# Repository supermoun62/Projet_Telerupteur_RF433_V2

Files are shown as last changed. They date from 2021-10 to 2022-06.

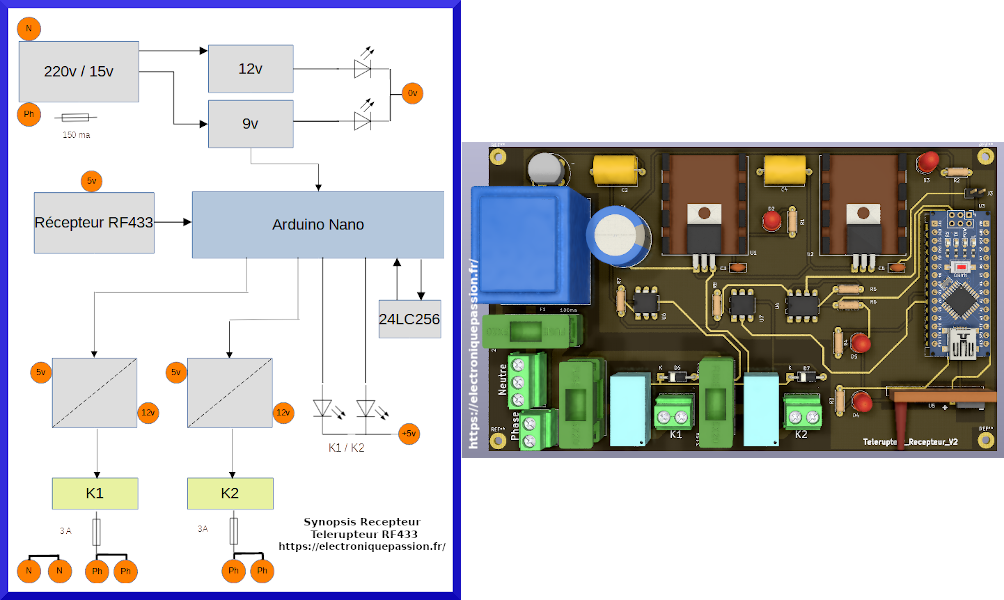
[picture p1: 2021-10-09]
Synopsis_PCB_Telerupteur_Recepteur_V2.png

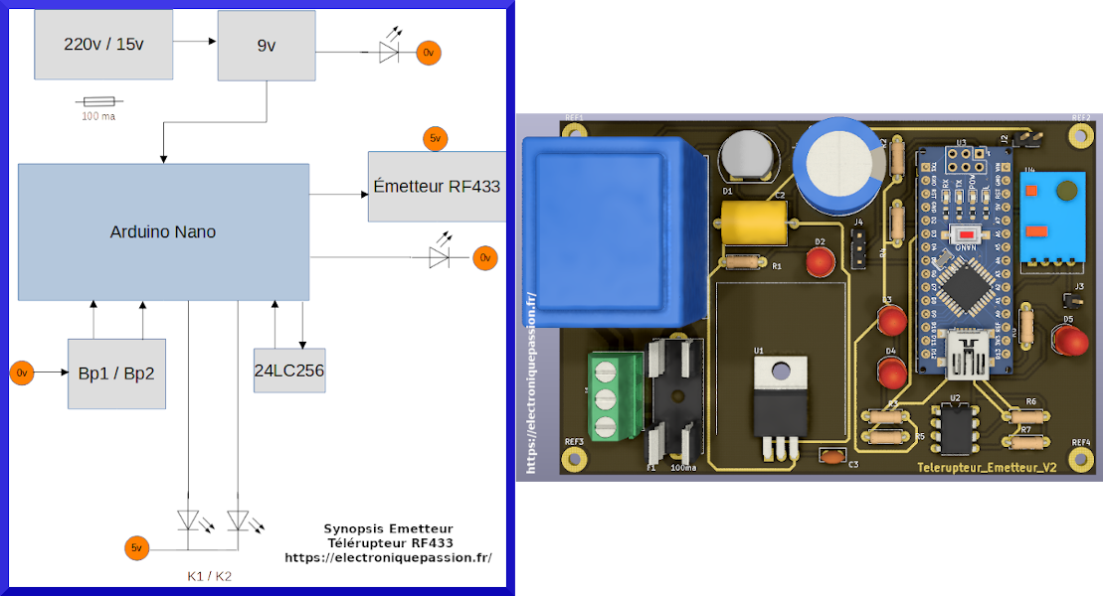
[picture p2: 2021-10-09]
Synopsis_PCB_Telerupteur_Emetteur_V2.png

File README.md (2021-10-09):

# Projet_Telerupteur_RF433_V2
Piloter des relais en RF433. L'ensemble comprend:

    Programmes Arduino de l'émetteur et du récepteur.

    Programmes Arduino Test.

    Librairies VirtualWire et simpleBouton.

    Liste du matériel.

    Les schémas (Emetteur, Récepteur).

    Documentations Techniques.

    PCB en Gerber.

    PCB en PDF.

    Le fichier Projet Telerupteur_RF433_V2.pdf contient le détail du projet.

    https://github.com/supermoun62/Projet_Telerupteur_RF433_V2/blob/main/Synopsis_PCB_Telerupteur_Emetteur_V2.png

    https://github.com/supermoun62/Projet_Telerupteur_RF433_V2/blob/main/Synopsis_PCB_Telerupteur_Recepteur_V2.png

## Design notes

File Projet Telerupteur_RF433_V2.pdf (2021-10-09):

## Projet Télérupteur_RF433_V1 Projet

Arduino_Cde_Telerupteur_RF433_V2 | 1 sur 15 | https://electroniquepassion.fr/

# PROJET

Piloter deux relais en RF433.

Mémoriser l’état de la commande de chaque relais en cas de coupure de courant de l’émetteur.

## Plus d’info pour récupérer le projet sur le site:

## https://electroniquepassion.fr

## Projet Télérupteur_RF433_V1 Synopsis Emetteur

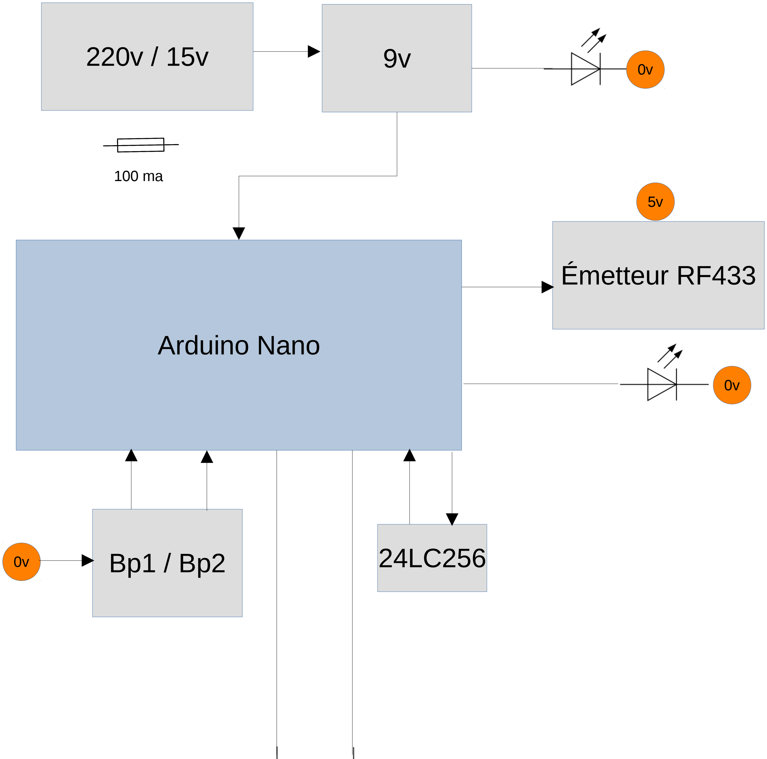
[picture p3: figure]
Arduino Nano; Émetteur RF433

5v
K1 / K2
Arduino_Cde_Telerupteur_RF433_V2 | 2 sur 15 | https://electroniquepassion.fr/

## Projet Télérupteur_RF433_V1 Synopsis Récepteur

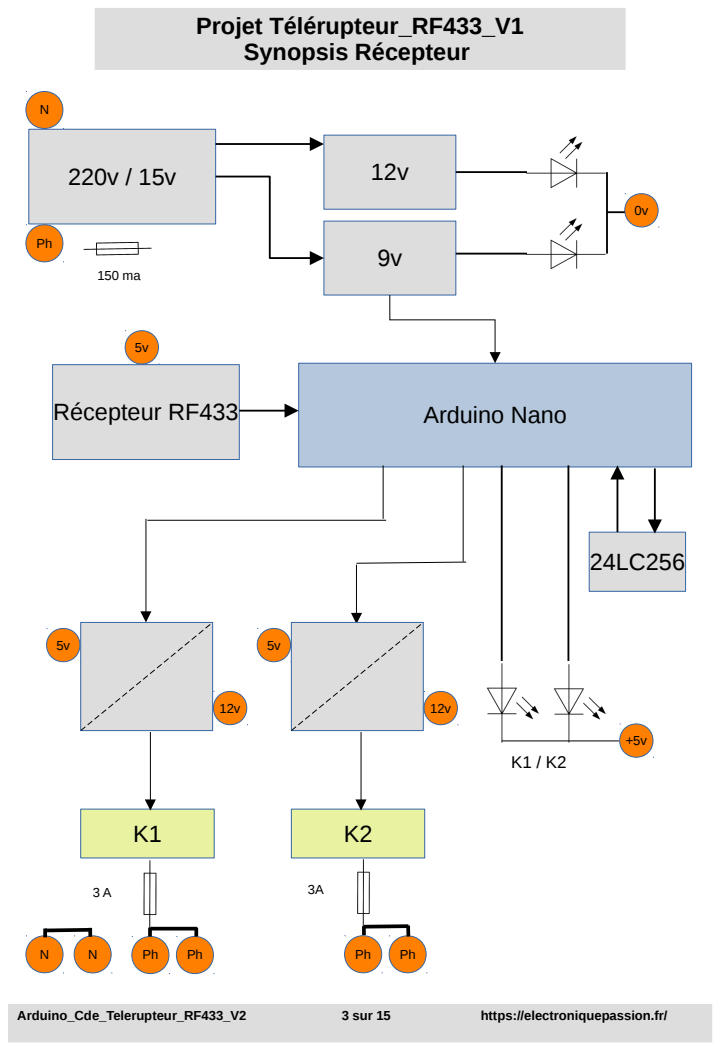
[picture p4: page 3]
Récepteur RF433; Arduino Nano; Arduino_Cde_Telerupteur_RF433_V2; 3 sur 15; https://electroniquepassion.fr/

## Dossier Matériels:

Projet_Telerupteur_RF433_V2\ Liste_Materiel_Emetteur_Recepteur_Telerupteur_RF433_V2

## Dossiers Documentations Techniques:

Projet_Telerupteur_RF433_V2\Doc_Tech_Emetteur_Recepteur_Telerupteur_RF433_V2

## Dossiers Schémas:

Projet_Telerupteur_RF433_V2\Schemas_Emetteur_Recepteur_Telerupteur_RF433_V2

## Dossiers PCB Emetteur en Gerber

Projet_Telerupteur_RF433_V2\PCB_GERBER_Telerupteur_Emetteur_V2

## Dossiers PCB Emetteur en PDF

Projet_Telerupteur_RF433_V2\PCB_PDF_Telerupteur_Emetteur_V2

## Programme Arduino Emetteur :

Projet_Telerupteur_RF433_V2\ArduinoTelerupteurEmissionRF433_V2

## Dossiers PCB Recepteur en Gerber

Projet_Telerupteur_RF433_V2\PCB_GERBER_Telerupteur_Recepteur_V2

## Dossiers PCB Emetteur en PDF

Projet_Telerupteur_RF433_V2\PCB_PDF_Telerupteur_Recepteur_V2

## Programme Arduino Récepteur :

Projet_Telerupteur_RF433_V2\ArduinoTelerupteurReceptionRF433_V2

## Projet Télérupteur_RF433_V1

Arduino_Cde_Telerupteur_RF433_V2 | 4 sur 15 | https://electroniquepassion.fr/

## Projet Télérupteur_RF433_V1

## Librairies:

Dossier VirtualWire13

VirtualWire V1,3 (http://www.airspayce.com/mikem/arduino/VirtualWire/index.html) | Airspace (https://www.airspayce.com/mikem/arduino/VirtualWire/VirtualWire_8h.html) | Github (https://github.com/m0/Updated-Arduino-VirtualWire-Library) | CarnetduMaker (https://www.carnetdumaker.net/articles/communiquer-sans-fil-en-433mhz-avec-la-bibliotheque-virtualwire-et-une-carte-arduino-genuino/)

Pjrc (https://www.pjrc.com/teensy/td_libs_VirtualWire.html)

Dossier simpleBouton V1.4.2

SimpleBouton (https://forum.arduino.cc/index.php?topic=375232.0)

24LC256 :

Lien 1 (https://lesiteferroviaire.pagesperso-orange.fr/Memoire%2024LC512.htm) | | Lien2 (http://electroniqueamateur.blogspot.com/2020/01/utiliser-une-memoire-eeprom-i2c-arduino.html) | Lien 3 (https://www.youtube.com/watch?v=9CpwQUzw1ys)

## Lecture totale 24LC256

Projet_Telerupteur_RF433_V2\24LC256LectureTotale

## Lecture - Ecriture 24LC256 :

Projet_Telerupteur_RF433_V2\ArduinoLectureEcriture_24LC256

## Test reception messages :

Projet_Telerupteur_RF433_V2\ArduinoTestReceptionMessage

## Programmes utilises :

LibreOffice Calc, LibreOffice Draw, Arduino,
Kicad, Freecad, FreeRouting Gimp
Arduino_Cde_Telerupteur_RF433_V2 | 5 sur 15 | https://electroniquepassion.fr/

## Fonctions de la librairie VirtualWire sont les suivantes:

extern void vw_set_tx_pin(uint8_t pin);

Pin utilisée pour transmettre les données, par défaut D12 de l’Arduino.

extern void vw_set_rx_pin(uint8_t pin);

Pin utilisée pour recevoir les données, par défaut D11 de l’Arduino.

extern void vw_set_ptt_pin(uint8_t pin); par défaut D10 de l’Arduino.

extern void vw_setup(uint16_t speed)

extern void vw_rx_start();

extern void vw_rx_stop();

extern uint8_t vx_tx_active();

extern void vw_wait_tx();

extern void vw_wait_rx();

extern uint8_t vw_wait_rx_max(unsigned long milliseconds);

extern uint8_t vw_send(uint8_t* buf, uint8_t len);

vw_send(byte* buf, byte len);

extern uint8_t vw_have_message();

extern uint8_t vw_get_message(uint8_t* buf, uint8_t* len); .

vw_MAX_MESSAGE_LEN ;

## D10, D11, D12 utilisées par défaut par Wirtualwire

## Arduino_Cde_Télérupteur_RF433_V1

Arduino_Cde_Telerupteur_RF433_V2 | 6 sur 15 | https://electroniquepassion.fr/

le 1/4 d'onde est la plus classique et la meilleure des antenne fouet (conducteur normal cuivre rigide ) longueur onde entière = vitesse de la lumière / fréquence
soit : 300 000 / 433 = 693 mm
1/4 d'onde = 173 mm

On peut réduire le résultat à 95%,
(effet de bout) donc 164,3 mm

## Site Lucea (http://www.lucea.fr/spip.php?article4)

## Fil utilisé pour l’antenne pendant les

essais.

## 35m sans obstacle

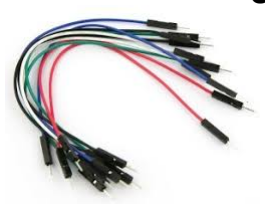
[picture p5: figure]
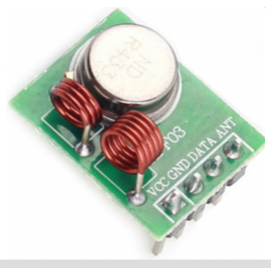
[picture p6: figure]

SEED STUDIO réf :113990010

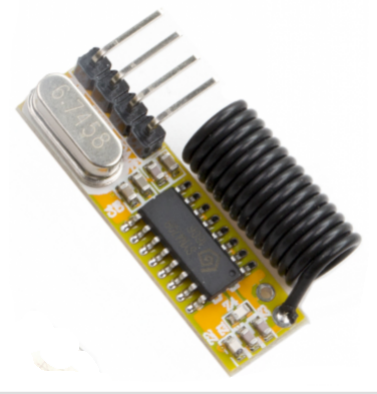
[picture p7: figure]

SEED STUDIO réf :113990010

Arduino_Cde_Telerupteur_RF433_V2 | 7 sur 15 | https://electroniquepassion.fr/

## Emetteur Calcul Refroidisseur Régulateur

Méthode utilisée : ICI (https://migia.pagesperso-orange.fr/electron/radiateur/radiateur.htm)

Rth ja | : 50°C/W
Rth jc | : 5°C/W
Tj Max | : 0-125° Prenons 100°
Ta | : 35°
Pâte | : 0,1°C/W
Is | : 0,2A

(5 + 0,1 + SA)

(100 - 35)
2 =

(Jc + CS + SA)

(Tj - Ta)
Pd =

2

65 – 10,2
SA =

SA = 27,4ºC/W Maximum

Pd = (Ue-Us)*I

(21-12)*0,2A = 1,8w, Prenons 2w

Lien 1 (https://fr.wikipedia.org/wiki/Loi_d'Ohm_thermique) | Lien 2 (https://migia.pagesperso-orange.fr/electron/radiateur/radiateur.htm) | Lien 3 (http://gdedel95.free.fr/STSETT/STS%20ETT2_2005-2006/Pdf/Choix%20dissipateur.PDF)
Arduino_Cde_Telerupteur_RF433_V2 | 8 sur 15 | https://electroniquepassion.fr/

## Emetteur

4N35

Lien1 (https://www.astuces-pratiques.fr/electronique/l-optocoupleur-principe-de-fonctionnement)

Pour les essais, j’ai utilisé le Joy-IT Nano-V3 de chez Joy-It.

Pour information, nécessite le driver : CH341SER.

Pour télécharger le programme, j'ai choisi :
ATmega328P (Old Bootloader)

Voir les infos sur la page :

## Joy-It (https://joy-it.net/en/products/ARD_NanoV3)

Arduino_Cde_Telerupteur_RF433_V2 | 9 sur 15 | https://electroniquepassion.fr/

## PCB Emetteur

Tracé du PCB :

Projet_Telerupteur_RF433_V2\

PCB_PDF_Telerupteur_Emetteur_V2\Telerupteur_Emetteur_RF433_V2-B_Cu.pdf

PCB_PDF_Telerupteur_Emetteur_V2\Telerupteur_Emetteur_RF433_V2-F_Cu.pdf

Implantation Composants :

Projet_Telerupteur_RF433_V2\

PCB_PDF_Telerupteur_Emetteur_V2\Telerupteur_Emetteur_RF433_V2-F_SilkS.pdf

Création du PCB

- Fabrication personnelle OU
- Sites en ligne comme :
Util'Pocket
JLCPCB
Etc....

Chez JLCPCB nécessite l'envoi du dossier compressé :

PCB_GERBER_Telerupteur_Emetteur_V2

Arduino_Cde_Telerupteur_RF433_V2 | 10 sur 15 | https://electroniquepassion.fr/

## PCB Emetteur

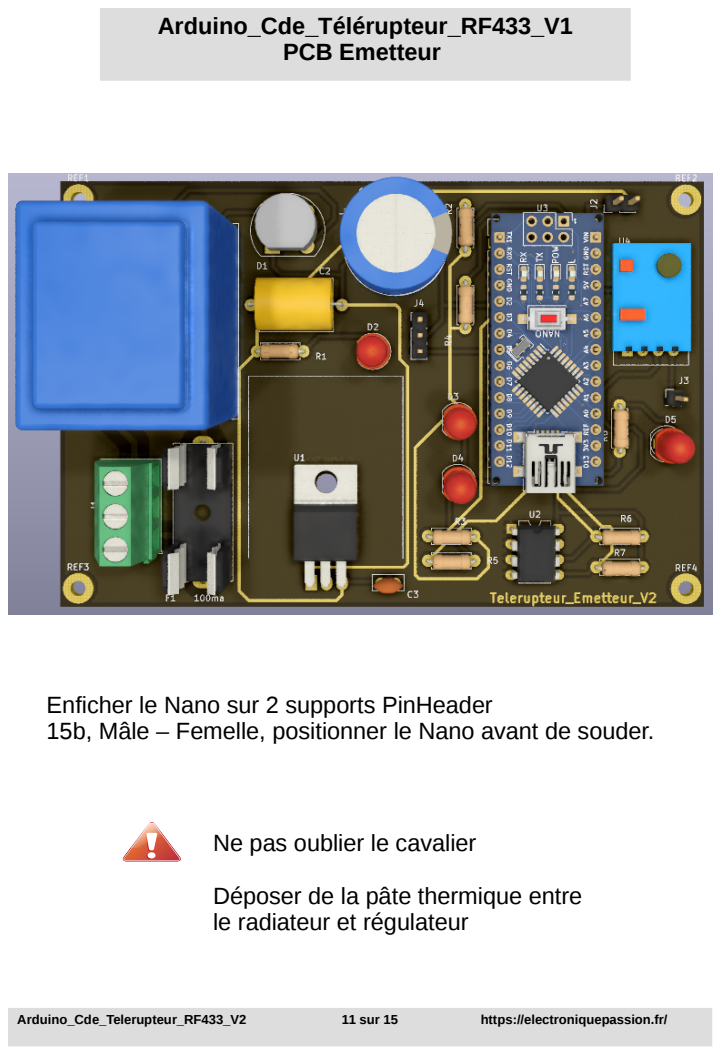
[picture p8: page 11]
Arduino_Cde_Telerupteur_RF433_V2; 11 sur 15; https://electroniquepassion.fr/

Enficher le Nano sur 2 supports PinHeader
15b, Mâle – Femelle, positionner le Nano avant de souder.

Ne pas oublier le cavalier

Déposer de la pâte thermique entre
le radiateur et régulateur

## PCB Tracé Emetteur

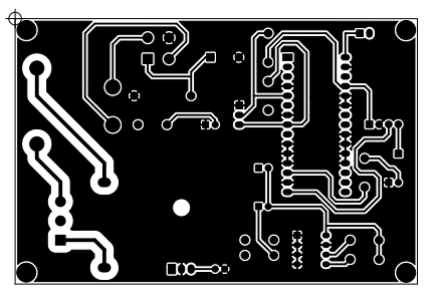
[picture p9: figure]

## Telerupteur_Emetteur_RF433_V2-B_Cu.pdf

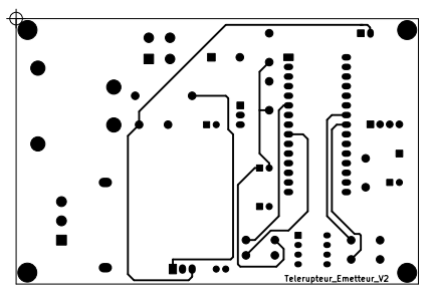
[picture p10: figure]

## Telerupteur_Emetteur_RF433_V2-F_Cu.pdf

Images pas
à l’échelle
Arduino_Cde_Telerupteur_RF433_V2 | 12 sur 15 | https://electroniquepassion.fr/

## PCB Récepteur

Tracé du PCB :

Projet_Telerupteur_RF433_V2\

PCB_PDF_Telerupteur_Recepteur_V2\Telerupteur_Recepteur_RF433_V2-B_Cu.pdf

PCB_PDF_Telerupteur_Recepteur_V2\Telerupteur_Recepteur_RF433_V2-F_Cu.pdf

Implantation Composants :

Projet_Telerupteur_RF433_V2\

PCB_PDF_Telerupteur_Recepteur_V2\Telerupteur_Recepteur_RF433_V2-F_SilkS.pdf

Création du PCB

- Fabrication personnelle OU
- Sites en ligne comme :
Util'Pocket
JLCPCB
Etc....

Chez JLCPCB nécessite l'envoi du dossier compressé :

PCB_GERBER_Telerupteur_Recepteur_V2

Arduino_Cde_Telerupteur_RF433_V2 | 13 sur 15 | https://electroniquepassion.fr/

## PCB Récepteur

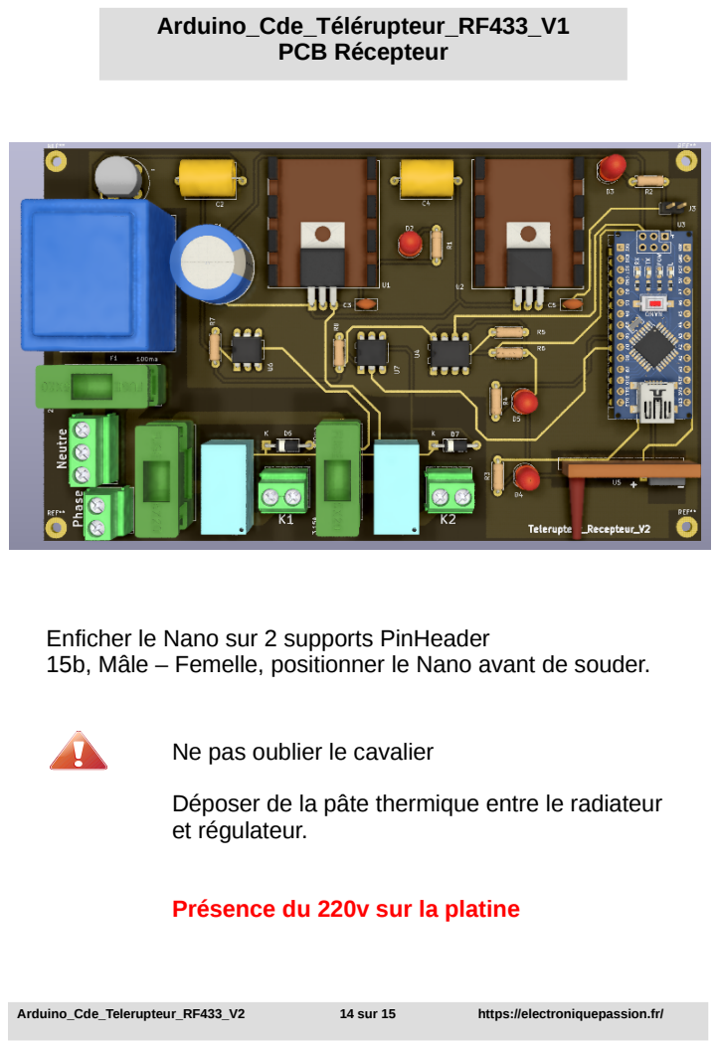
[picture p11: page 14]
Arduino_Cde_Telerupteur_RF433_V2; 14 sur 15; https://electroniquepassion.fr/

Enficher le Nano sur 2 supports PinHeader
15b, Mâle – Femelle, positionner le Nano avant de souder.

Ne pas oublier le cavalier

Déposer de la pâte thermique entre le radiateur
et régulateur.

Présence du 220v sur la platine

## PCB tracé Récepteur

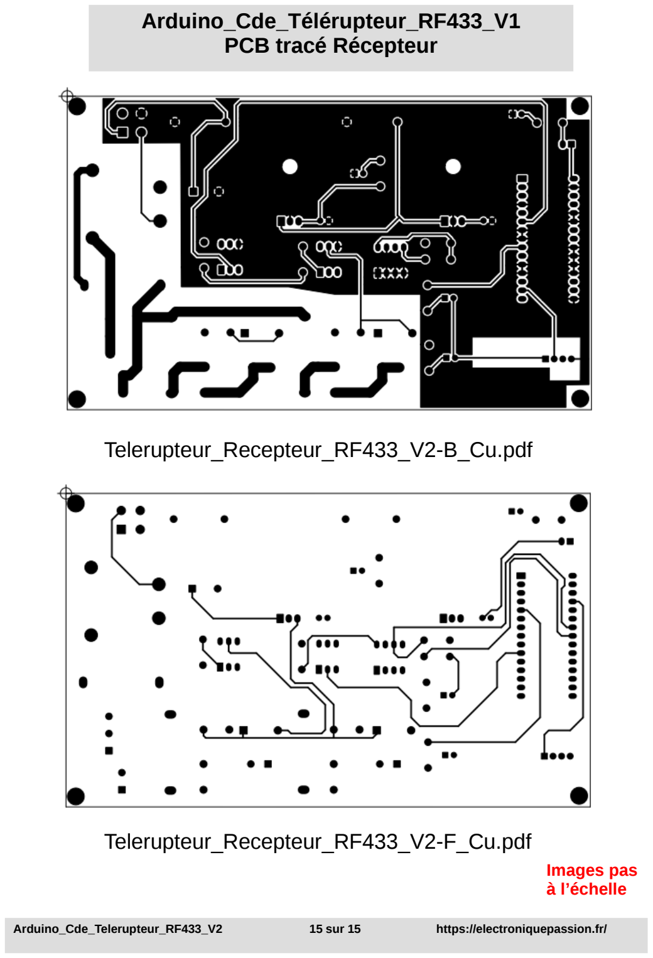
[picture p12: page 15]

## Telerupteur_Recepteur_RF433_V2-F_Cu.pdf

## Telerupteur_Recepteur_RF433_V2-B_Cu.pdf

Images pas
à l’échelle
Arduino_Cde_Telerupteur_RF433_V2 | 15 sur 15 | https://electroniquepassion.fr/

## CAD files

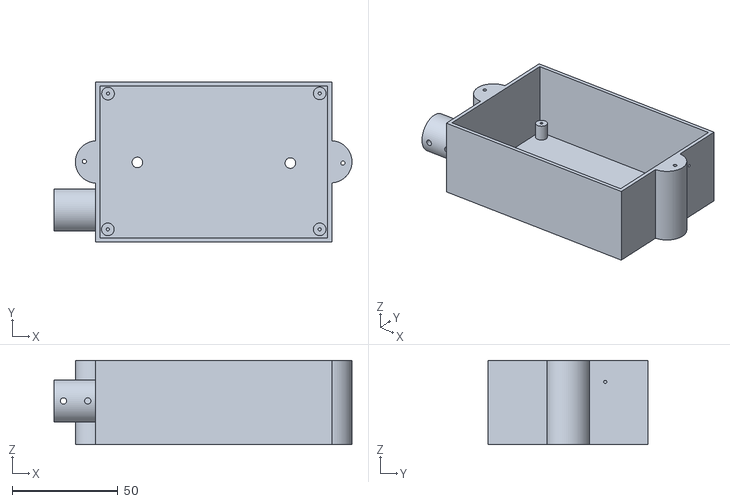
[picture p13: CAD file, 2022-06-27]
Fichiers_STL/Coffret emetteur Telerupteur RF433.stl
141.2 x 76.0 x 40.0

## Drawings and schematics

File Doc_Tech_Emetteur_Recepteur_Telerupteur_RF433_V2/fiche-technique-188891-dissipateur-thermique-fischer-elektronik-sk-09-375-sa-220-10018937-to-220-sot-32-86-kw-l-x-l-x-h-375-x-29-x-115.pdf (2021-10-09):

Art. Nr.

# Standardstrangkühlkörper

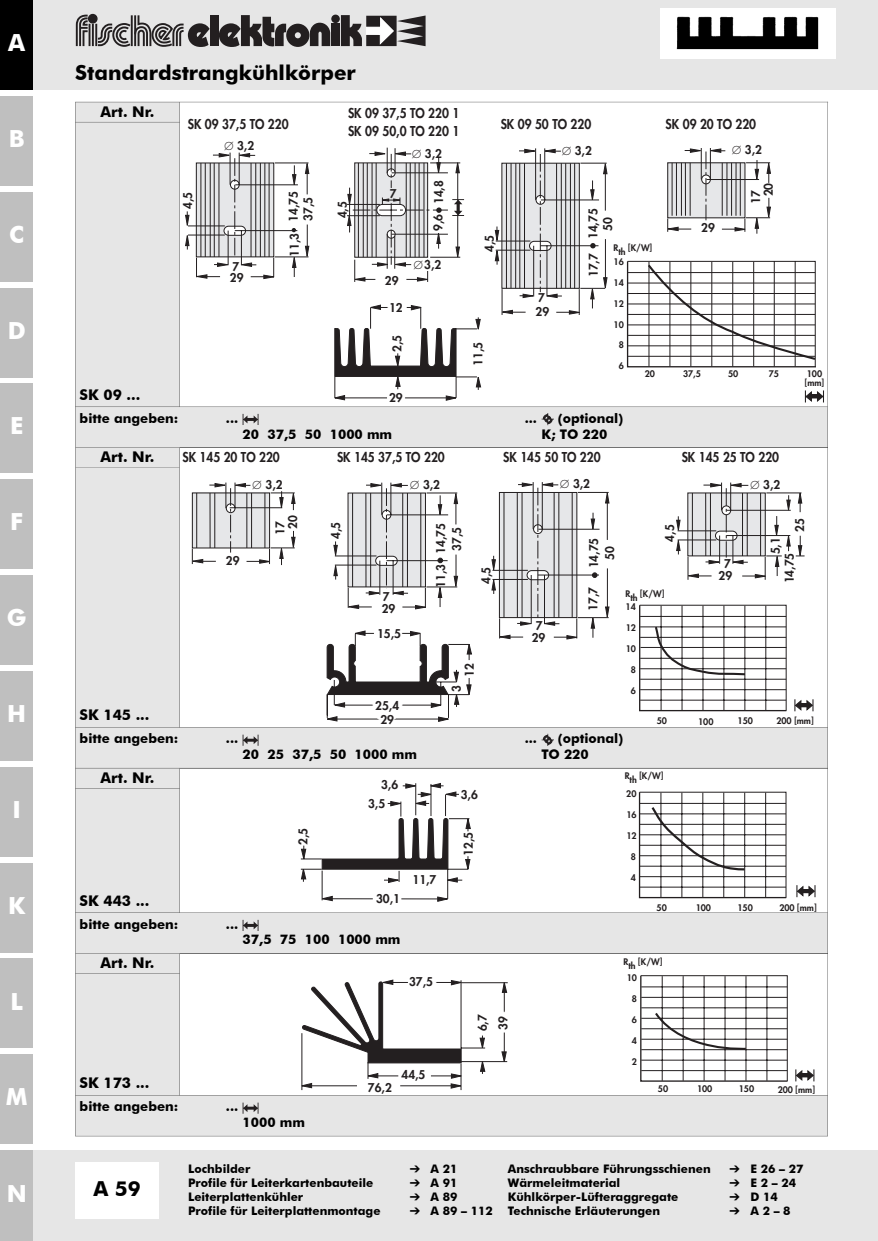
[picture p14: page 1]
(optional); bitte angeben:; Art. Nr.; Lochbilder; Anschraubbare Führungsschienen; Profile für Leiterkartenbauteile; Wärmeleitmaterial; Leiterplattenkühler; Kühlkörper-Lüfteraggregate; Profile für Leiterplattenmontage; Technische Erläuterungen

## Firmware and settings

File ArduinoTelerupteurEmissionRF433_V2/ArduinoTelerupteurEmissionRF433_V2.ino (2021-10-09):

/* Synopsis: Emission Telerupteur RF433 avec memorisation de l'etat 
   Carte   : Arduino Nano
   Capteur : Emetteur 433.   
             
   Biblio  : VirtualWire 1.3 
             simpleBouton.h 1.4.2 
             Wire
             
   Source  : http://www.airspayce.com/mikem/arduino/VirtualWire/index.html
             https://forum.arduino.cc/index.php?topic=375232.0 
             https://lesiteferroviaire.pagesperso-orange.fr/Memoire%2024LC512.htm
             http://electroniqueamateur.blogspot.com/2020/01/utiliser-une-memoire-eeprom-i2c-arduino.html 

   C.Mercier  62128 Boiry-Becquerelle  
*/
//-------------------------------------------------
#include <Wire.h>
#define adresse_EEPROM 0x50 //Addresse i2c de l'EEPROM
  int adresseK1 = 10;
  int donneeK1 = 0;
  int adresseK2 = 20;
  int donneeK2 = 0;
//-------------------------------------------------
//librairie simpleBouton.h
//Cablage : pin---BP---GND
#include "simpleBouton.h"
  const uint8_t PINBP1 = 2;//Pin Nano 5
  const uint8_t PINBP2 = 5;//Pin Nano 8
  simpleBouton bouton1(PINBP1);
  simpleBouton bouton2(PINBP2);
//-------------------------------------------------
#include <VirtualWire.h>
//const int PINPTT = 10; // Pin Nano 13 
//const int PINDATAINPUT = 11; // Pin Nano 14 
//const int PINDATAOUT = 12; // Pin Nano 15
int pin_led = 13;//copie PINPTT
//-------------------------------------------------
  int ledK1=3;//Pin Nano 6
  bool memK1 = 0;//memoire K1
  bool envoiMessK1ON = 0;//memoire message K1 ON
  bool envoiMessK1OFF = 1;//memoire message K1 ON
  unsigned long tpsCourantK1ON = 0;
  unsigned long tpsEnvoiMessK1ON = 220;//A modifier si nécessaire;
  unsigned long tpsCourantK1OFF = 1;
  unsigned long tpsEnvoiMessK1OFF = 220;//A modifier si nécessaire;
//-------------------------------------------------
  int ledK2=6;//Pin Nano 9
  bool memK2;//memoire K2
  bool envoiMessK2ON = 0;//memoire message K2 ON
  bool envoiMessK2OFF = 1;//memoire message K2 ON
  unsigned long tpsCourantK2ON = 0;
  unsigned long tpsEnvoiMessK2ON = 220;//A modifier si nécessaire;
  unsigned long tpsCourantK2OFF = 1;
  unsigned long tpsEnvoiMessK2OFF = 220;//A modifier si nécessaire;
//-------------------------------------------------
  bool bitDemarrage = 1;
  int valeurTest = 0;
//*************************************************
void setup()
  { 
    Wire.begin();//déclare maitre sur le bus i2c
//-------------------------------------------------  
    //vw_set_ptt_pin(PINPTT);
    //vw_set_rx_pin(PINDATAINPUT);
    //vw_set_tx_pin(PINDATAOUT);// On peut changer les pins rx,tx,ptt AVANT vw_setup() si util.
    vw_setup(2000);// Bits par seconde  
    vw_rx_start();// Démarre la partie réception de la librairie VirtualWire.
    pinMode(pin_led,OUTPUT);
    digitalWrite(pin_led,LOW);
//-------------------------------------------------
    pinMode (PINBP1,INPUT);
    pinMode(ledK1,OUTPUT);
    digitalWrite(ledK1,HIGH);
    pinMode (PINBP2,INPUT);
    pinMode(ledK2,OUTPUT);
    digitalWrite(ledK2,HIGH);           
//-------------------------------------------------    
    Serial.begin(9600);
    delay(2000);
  }//FIN SETUP
//*************************************************
void loop()
{
if(bitDemarrage==1)
  {  
lectureAdresseK1();
    if(donneeK1 == 1)
        {
          memK1 =1; 
          envoiMessK1OFF = 0;    
        } 
    else
        {
          memK1 = 0;
          envoiMessK1ON = 0;      
        } 
lectureAdresseK2();               
    if(donneeK2 == 1)    
        {
          memK2 =1;
          envoiMessK2OFF = 0;     
        } 
    else
        {
          memK2 = 0;
          envoiMessK2ON = 0;      
        }                    
  }
bouton1.actualiser();  
if (bouton1.vientDEtreEnfonce() )
  { 
    memK1 =! memK1;    
    ecritureAdresseK1();              
    if (memK1 == 1 && envoiMessK1ON == 0)
      {
        tpsCourantK1ON = millis();
      }
        if (memK1 == 0 && envoiMessK1OFF == 0)
          {
            tpsCourantK1OFF = millis();
          }                  
  }
//*************************************************
bouton2.actualiser();  
if (bouton2.vientDEtreEnfonce() )
  { 
    memK2 =! memK2;
    ecritureAdresseK2();    
    if (memK2 == 1 && envoiMessK2ON == 0)
      {
        tpsCourantK2ON = millis();
      }
        if (memK2 == 0 && envoiMessK2OFF == 0)
          {
            tpsCourantK2OFF = millis();
          }        
  }  
//*************************************************  
envoiMessageK1ON(); 
envoiMessageK1OFF(); 
envoiMessageK2ON(); 
envoiMessageK2OFF(); 
//*************************************************
if(memK1 == 1)
  {
    digitalWrite(ledK1, LOW);    
  }
else
  {
    digitalWrite(ledK1, HIGH);    
  }
if(memK2 == 1)
  {
    digitalWrite(ledK2, LOW);
  }
else
  {
    digitalWrite(ledK2, HIGH);  
  }
//*************************************************
//Serial.println(memK1); 
//Serial.print("\t");
//Serial.println(envoiMessK1OFF);
bitDemarrage = 0;  
}//FIN LOOP
//*************************************************
void lectureAdresseK1()
{
  Wire.beginTransmission(adresse_EEPROM); //adresse 24LC256
  Wire.write(adresseK1>>8);//position adresse 24LC256- Octet le plus significatif
  Wire.write(adresseK1 & 0xFF);//position adresse 24LC256- Octet le moins significatif
  Wire.endTransmission();
  Wire.requestFrom(adresse_EEPROM,1);//adresse et quantite 1 octet 
  delay(5); 
  donneeK1 = Wire.read();  
}
//*************************************************
void ecritureAdresseK1()
{  
  Wire.beginTransmission(adresse_EEPROM);
  Wire.write(adresseK1>>8);//position adresse 24LC256- Octet le plus significatif
  Wire.write(adresseK1 & 0xFF);//position adresse 24LC256- Octet le moins significatif
  Wire.write(memK1);
  Wire.endTransmission();
  delay(5); 
}
//*************************************************
void lectureAdresseK2()
{
  Wire.beginTransmission(adresse_EEPROM); //adresse 24LC256
  Wire.write(adresseK2>>8);//position adresse 24LC256- Octet le plus significatif
  Wire.write(adresseK2 & 0xFF);//position adresse 24LC256- Octet le moins significatif
  Wire.endTransmission();
  Wire.requestFrom(adresse_EEPROM,1);//adresse et quantite 1 octet
  delay(5); 
  donneeK2 = Wire.read();   
}
//*************************************************
void ecritureAdresseK2()
{  
  Wire.beginTransmission(adresse_EEPROM);
  Wire.write(adresseK2>>8);//position adresse 24LC256- Octet le plus significatif
  Wire.write(adresseK2 & 0xFF);//position adresse 24LC256- Octet le moins significatif
  Wire.write(memK2);
  Wire.endTransmission();
  delay(5); 
}
//*************************************************
void envoiMessageK1ON()
{
if(( millis()-tpsCourantK1ON < tpsEnvoiMessK1ON) && memK1 == 1)
  {
    const char *msg="Relais1ON";
    vw_send((uint8_t *)msg, strlen(msg)); //Envoi du message
    vw_wait_tx();//Attend la fin de la transmission en cours
    envoiMessK1ON = 1;
    envoiMessK1OFF = 0;     
  }  
}
//*************************************************
void envoiMessageK1OFF()
{
if(( millis()-tpsCourantK1OFF < tpsEnvoiMessK1OFF) && memK1 == 0)
  {
    const char *msg="Relais1OFF";
    vw_send((uint8_t *)msg, strlen(msg)); //Envoi du message
    vw_wait_tx();//Attend la fin de la transmission en cours
    envoiMessK1OFF = 1;
    envoiMessK1ON = 0;
  } 
}
//*************************************************
void envoiMessageK2ON()
{
if(( millis()-tpsCourantK2ON < tpsEnvoiMessK2ON) && memK2 == 1)
  {
    const char *msg="Relais2ON";
    vw_send((uint8_t *)msg, strlen(msg)); //Envoi du message
    vw_wait_tx();//Attend la fin de la transmission en cours
    envoiMessK2ON = 1;
    envoiMessK2OFF = 0;
  }
}  
//*************************************************  
void envoiMessageK2OFF()
{
if(( millis()-tpsCourantK2OFF < tpsEnvoiMessK2OFF) && memK2 == 0)
  {
    const char *msg="Relais2OFF";
    vw_send((uint8_t *)msg, strlen(msg)); //Envoi du message
    vw_wait_tx();//Attend la fin de la transmission en cours
    envoiMessK2OFF = 1;
    envoiMessK2ON = 0;
  }
}

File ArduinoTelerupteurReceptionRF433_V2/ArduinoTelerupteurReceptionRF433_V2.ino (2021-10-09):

/*
   Synopsis: Reception Telerupteur RF433 avec memorisation de l'etat
   Carte   : Arduino nano
   Capteur : Recepteur 433
      
   Biblio  : VirtualWire 1.3
             Wire 

   Source  : http://www.airspayce.com/mikem/arduino/VirtualWire/index.html
             https://forum.arduino.cc/index.php?topic=375232.0 

             https://github.com/m0/Updated-Arduino-VirtualWire-Library
             https://www.carnetdumaker.net/articles/communiquer-sans-fil-en-433mhz-avec-la-bibliotheque-virtualwire-et-une-carte-arduino-genuino/ 
             
             http://www.lucea.fr/spip.php?article4
             
             https://lesiteferroviaire.pagesperso-orange.fr/Memoire%2024LC512.htm
             http://electroniqueamateur.blogspot.com/2020/01/utiliser-une-memoire-eeprom-i2c-arduino.html 
    
   C. Mercier 62128 Boiry-Becquerelle
*/
//-----------------------------------
  #include <Wire.h>
  #define adresse_EEPROM 0x50 //Addresse i2c de l'EEPROM
  int adresseK1 = 10;
  int donneeK1 = 0;
  int adresseK2 = 20;
  int donneeK2 = 0;
//-------------------------------------------------
  #include <VirtualWire.h>
//const int PINPTT = 10; // Pin Nano 13 
//const int PINDATAINPUT = 11; // Pin Nano 14 
//const int PINDATAOUT = 12; // Pin Nano 15
//-----------------------------------
  const int PINLEDK1 = 2;// Pin Nano 5
  const int PINK1 = 3;// Pin Nano 6
  const int PINLEDK2 = 6;// Pin Nano 9
  const int PINK2 = 7;// Pin Nano 10
  bool K1;
  bool memK1;
  bool bitK1;
  bool K2;
  bool memK2;
  bool bitK2;
  bool bitDemarrage;
//*************************************************
void setup()
{
Wire.begin();//déclare maitre sur le bus i2c  
//-----------------------------------  
/* On peut changer les pins rx,tx,ptt AVANT vw_setup() si util.     
   vw_set_ptt_pin(PINPTT);
   vw_set_rx_pin(PINDATAINPUT);
   vw_set_tx_pin(PINDATAOUT);// 
*/   
vw_setup(2000);// Bits par seconde  
vw_rx_start();// Démarre la partie réception de la librairie VirtualWire.
//-----------------------------------
    pinMode(PINLEDK1, OUTPUT); 
    pinMode(PINK1, OUTPUT);
    digitalWrite(PINLEDK1, HIGH);
    digitalWrite(PINK1, HIGH);
    pinMode(PINLEDK2, OUTPUT);
    pinMode(PINK2, OUTPUT);
    digitalWrite(PINLEDK2, HIGH); 
    digitalWrite(PINK2, HIGH);
//-----------------------------------    
  K1 = 0; 
  memK1 = 0;
  bitK1 = 0;
  K2 = 0;
  memK2 = 0;
  bitK2 = 0;
  bitDemarrage = 1;
  Serial.begin(9600);
  delay(2000); 
}//FIN SETUP
//*************************************************
void loop()
{
if(bitDemarrage==1)
  {  
lectureAdresseK1();
    if(donneeK1 == 1)
        {
          K1 = 1; 
        } 
    else
        {
          K1 = 0;
        } 
lectureAdresseK2();               
    if(donneeK2 == 1)    
        {
          K2 = 1;
        } 
    else
        {
          K2 = 0;
        }                    
  }  
uint8_t buf[VW_MAX_MESSAGE_LEN];
uint8_t buflen = VW_MAX_MESSAGE_LEN;      
if ( vw_get_message(buf, &buflen) ) // Lit le dernier message reçu
  { 
    if ((buflen==9) && (strncmp((char*)buf,"Relais1ON",9)) == 0) 
      {        
        K1 = 1;    
      }      
    if ((buflen==10) && (strncmp((char*)buf,"Relais1OFF",10)) == 0) 
      {        
        K1 = 0;  
      }
    if ((buflen==9) && (strncmp((char*)buf,"Relais2ON",9)) == 0) 
      {
        K2 = 1;    
      }      
    if ((buflen==10) && (strncmp((char*)buf,"Relais2OFF",10)) == 0) 
      {
        K2 = 0;  
      } 
  }//FIN GET 

if((K1 == 1) )
  {
    digitalWrite(PINLEDK1, LOW); 
    digitalWrite(PINK1, LOW);     
  }
else
  {
    digitalWrite(PINLEDK1, HIGH);
    digitalWrite(PINK1, HIGH);
  }
if(K2 == 1)
  {
    digitalWrite(PINLEDK2, LOW);
    digitalWrite(PINK2, LOW);      
  }
else
  {
    digitalWrite(PINLEDK2, HIGH);
    digitalWrite(PINK2, HIGH);
  }
if(K1==1 && bitK1 ==0)
  {
    memK1 = 1;
    ecritureAdresseK1();
    bitK1 = 1;    
  }
if(K1==0 && bitK1 ==1)
  {
    memK1 = 0;
    ecritureAdresseK1();
    bitK1 = 0;   
  }
if(K2==1 && bitK2 ==0)
  {
    memK2 = 1;
    ecritureAdresseK2();
    bitK2 = 1;    
  }
if(K2==0 && bitK2 ==1)
  {
    memK2 = 0;
    ecritureAdresseK2();
    bitK2 = 0;   
  }
  
//Serial.println(memK1);
bitDemarrage = 0;
} //FIN LOOP
//*************************************************
void lectureAdresseK1()
{
  Wire.beginTransmission(adresse_EEPROM); //adresse 24LC256
  Wire.write(adresseK1>>8);//position adresse 24LC256- Octet le plus significatif
  Wire.write(adresseK1 & 0xFF);//position adresse 24LC256- Octet le moins significatif
  Wire.endTransmission();
  Wire.requestFrom(adresse_EEPROM,1);//adresse et quantite 1 octet 
  delay(5); 
  donneeK1 = Wire.read();  
}
//*************************************************
void ecritureAdresseK1()
{  
  Wire.beginTransmission(adresse_EEPROM);
  Wire.write(adresseK1>>8);//position adresse 24LC256- Octet le plus significatif
  Wire.write(adresseK1 & 0xFF);//position adresse 24LC256- Octet le moins significatif
  Wire.write(memK1);
  Wire.endTransmission();
  delay(5); 
}
//*************************************************
void lectureAdresseK2()
{
  Wire.beginTransmission(adresse_EEPROM); //adresse 24LC256
  Wire.write(adresseK2>>8);//position adresse 24LC256- Octet le plus significatif
  Wire.write(adresseK2 & 0xFF);//position adresse 24LC256- Octet le moins significatif
  Wire.endTransmission();
  Wire.requestFrom(adresse_EEPROM,1);//adresse et quantite 1 octet
  delay(5); 
  donneeK2 = Wire.read();   
}
//*************************************************
void ecritureAdresseK2()
{  
  Wire.beginTransmission(adresse_EEPROM);
  Wire.write(adresseK2>>8);//position adresse 24LC256- Octet le plus significatif
  Wire.write(adresseK2 & 0xFF);//position adresse 24LC256- Octet le moins significatif
  Wire.write(memK2);
  Wire.endTransmission();
  delay(5); 
}
//*************************************************

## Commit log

2021-10-09 C. Mercier 1er Commit 09/10/2021
    [Telerupteur_Emetteur_RF433_V2-B_CrtYd.gbr, Telerupteur_Emetteur_RF433_V2-B_Cu.gbr, Telerupteur_Emetteur_RF433_V2-B_Fab.gbr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]
2022-06-27 C.Mercier Ajout fichiers STL 27/07/2022O
    [Coffret emetteur Telerupteur RF433.stl]
2022-06-27 C. Mercier suppression Fichiers STL 27/07/2022
    [Coffret emetteur Telerupteur RF433.stl]
2022-06-27 C. Mercier Ajout Dossier Fichiers_STL 27/06/2022
    [Coffret emetteur Telerupteur RF433.stl]
